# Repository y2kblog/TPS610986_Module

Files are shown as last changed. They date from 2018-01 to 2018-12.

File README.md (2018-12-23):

# TPS610986 超低消費電力 3.3V出力昇圧モジュール

<!--
<img src="/images/ProductImage_Front.jpg" width="200px">
-->
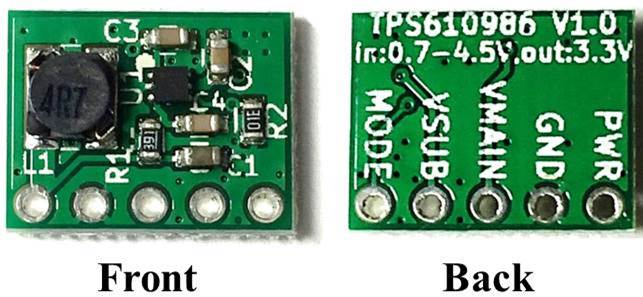
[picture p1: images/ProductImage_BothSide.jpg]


## 概要

超低消費電力の昇圧型DC-DCコンバータ TPS610986 (Texas Instruments Inc.製) を搭載したモジュールです。  
TPS610986の**静止電流は約1μA程度**（ローパワーモード時）と非常に低く、また**0.7Vから動作**するため、コイン電池1個、もしくはアルカリ／ニカド／ニッケル水素乾電池1～2本で駆動するアプリケーションに適しています。  
さらに、TPS610986は**ロードスイッチ機能付き**であり、MODEピンを利用することでVSUBピンのON/OFFの切り替えとローパワーモード（超低静止電流）／アクティブモード（高過渡応答）の選択が可能です。  
これにより、定期的にウェイクアップして動作し、それ以外の大半の時間はスリープするようなバッテリー駆動のアプリケーションにおいて、常時出力のVMAINピンをマイコン（MCU）に繋ぎ、VSUBピンをその他のサブシステム（センサ、GPS、無線モジュール、SDカード等）に接続すると、スリープ時はローパワーモードでマイコンのみに電力を供給することでバッテリー寿命を延ばし、動作時はアクティブモードでサブシステムにも高過渡応答の安定的な電力を供給する、といったことが可能です。  
<!--
TPS610986の静止電流は約1μA程度（ローパワーモード時）と非常に低いため、バッテリー駆動のアプリケーションに適しています。  
-->
<!--
スリープ時はローパワーモードでマイコンのみに電力を供給することでバッテリー寿命を延ばし、ウェイクアップ時はアクティブモードで良好な過渡応答を得ることができます。  
また、最大スイッチング電流は350mAであるため、SDカード等の比較的大電流を要するアプリケーションにも使用できます。
-->

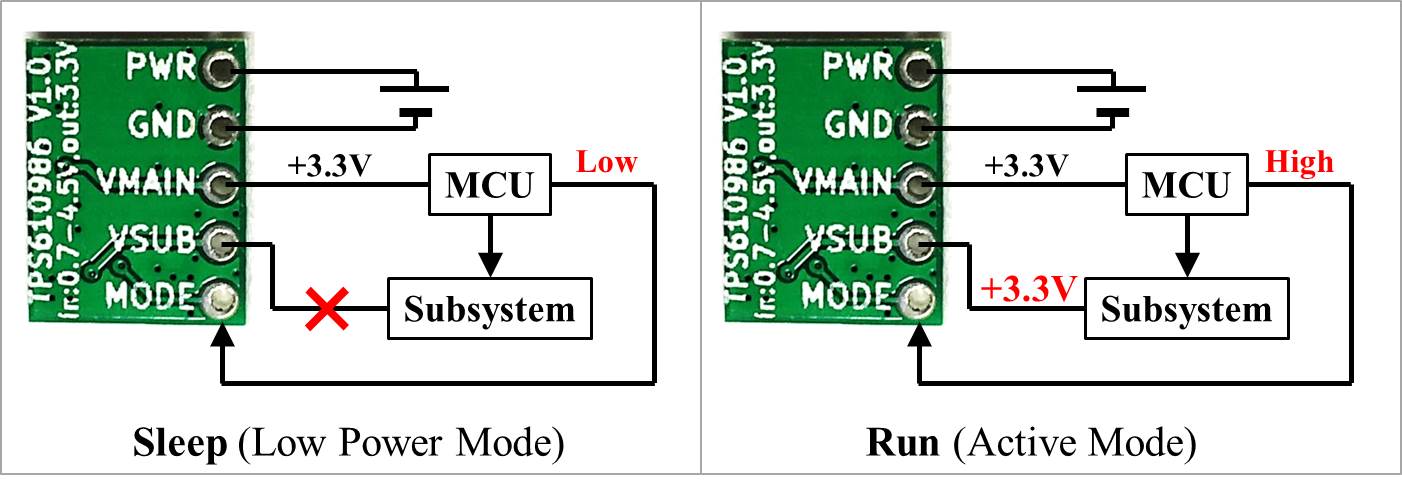
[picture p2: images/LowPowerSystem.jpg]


### 仕様
- 入力電圧：0.7V～4.5V (※3.3V以上入力した場合はパススルーとなります)
- 出力電圧：3.3V (低負荷のバーストモード時：3.4V)
- 最大スイッチング電流：350mA (※最大出力電流は入力電圧と効率に依存します)
- ロードスイッチ付
- 効率
  - 88% (入力電圧2V～3.3V、負荷10μA、ローパワーモード時)
  - 93% (入力電圧2V～3.3V、負荷5mA～100mA)
- 基板サイズ：横12.7mm×縦10.0ｍｍ

## 販売  
[スイッチサイエンス委託販売ページ](https://www.switch-science.com/catalog/3659/)  
※大量注文や在庫に関する問い合わせは[こちら](mailto:info.y2kb@gmail.com)までご連絡ください。  

### 回路図  
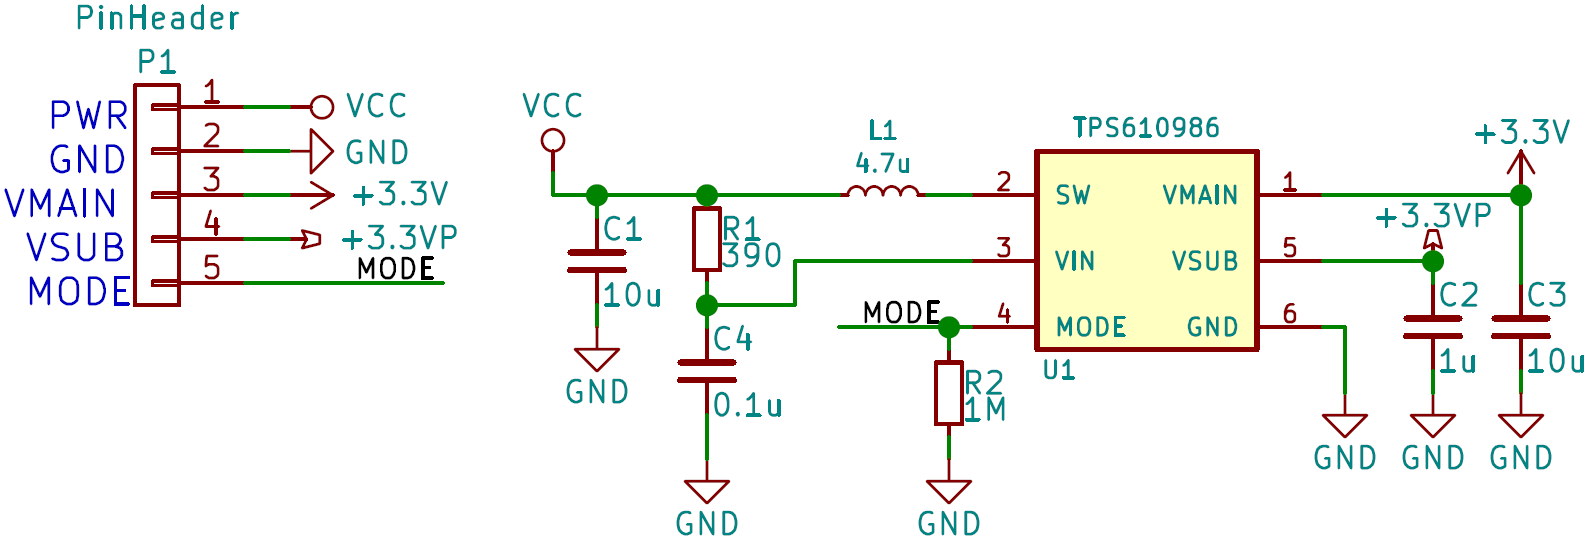
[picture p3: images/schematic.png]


### 寸法
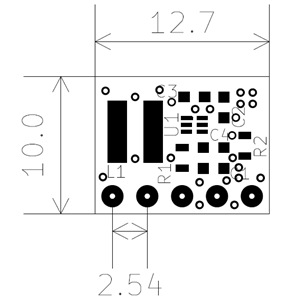
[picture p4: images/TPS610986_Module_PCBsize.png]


## 性能評価  

### 静止電流  
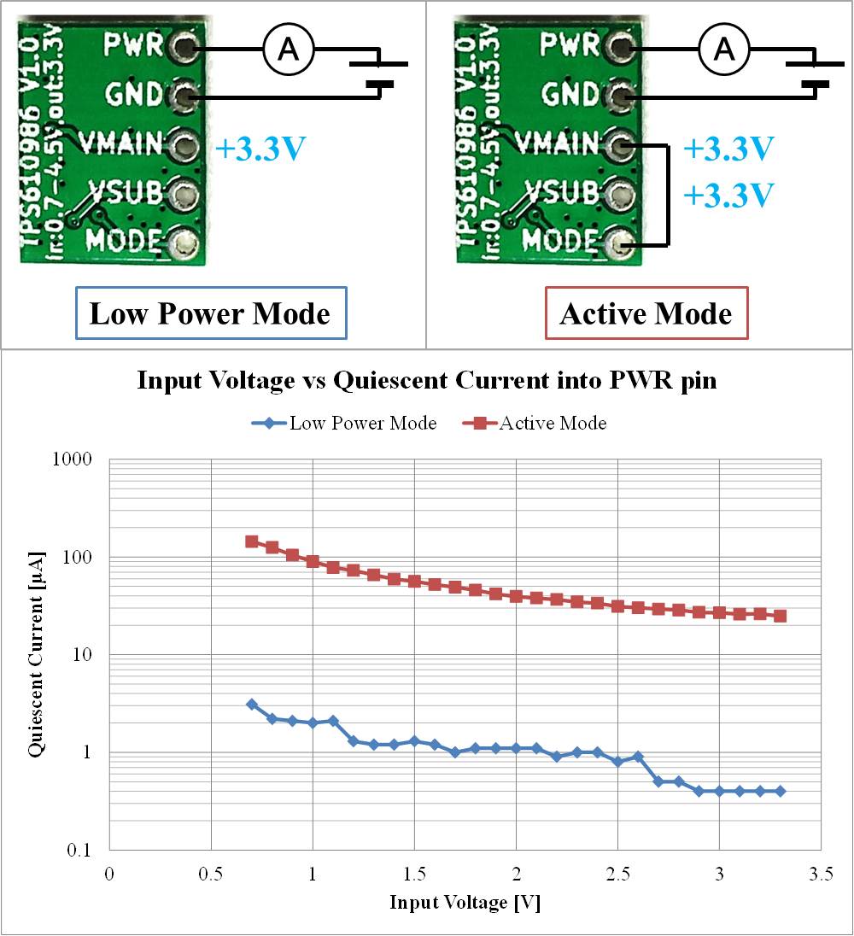
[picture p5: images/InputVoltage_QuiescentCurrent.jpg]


### 整定時間  

#### VSUBピンの整定時間（負荷：無し）：約800μs
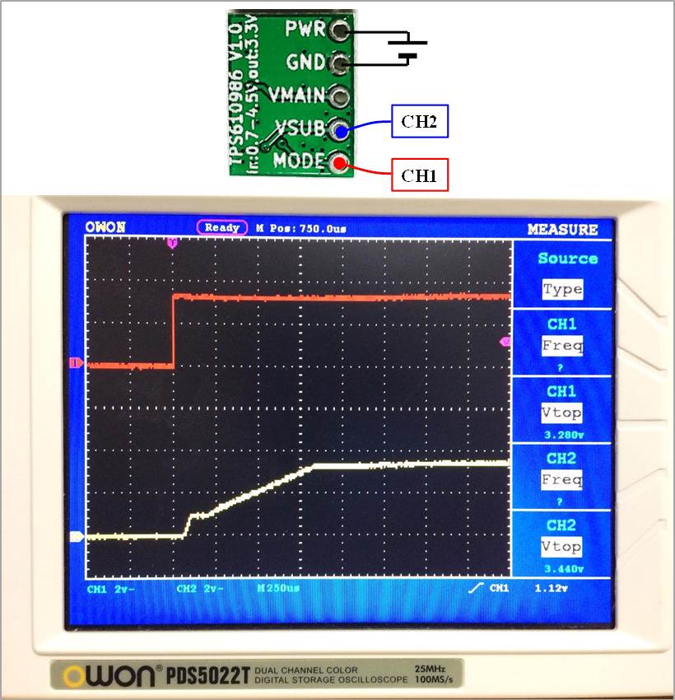
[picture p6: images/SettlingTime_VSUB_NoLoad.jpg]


#### VSUBピンの整定時間（負荷：210mA）：約760μs
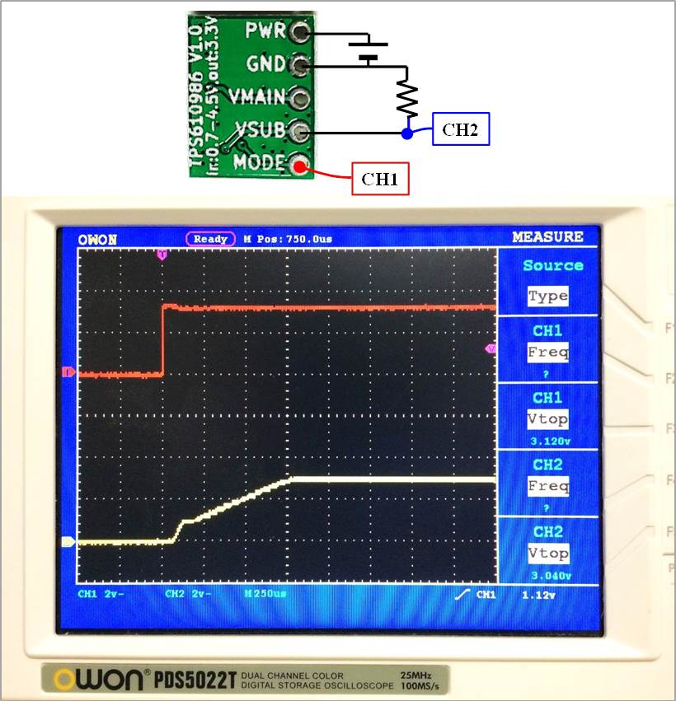
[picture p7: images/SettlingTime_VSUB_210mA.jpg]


#### VMAINピンの整定時間（負荷：無し）：約580μs
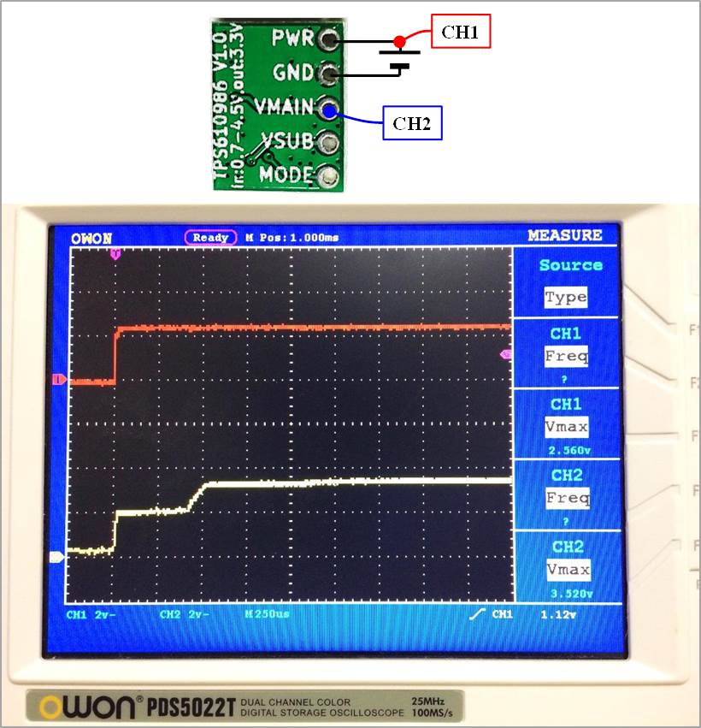
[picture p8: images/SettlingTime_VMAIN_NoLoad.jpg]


#### VMAINピンの整定時間（負荷：210mA）：約1500μs
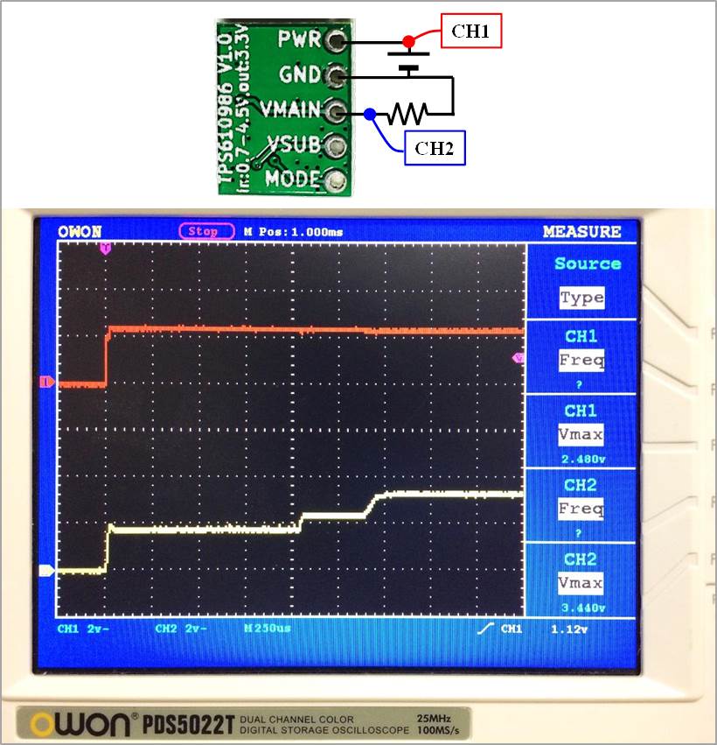
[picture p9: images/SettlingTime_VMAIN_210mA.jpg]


## データシート  
[TPS610986データシート(英語)](http://www.ti.com/lit/ds/symlink/tps610986.pdf)

## License
MIT License

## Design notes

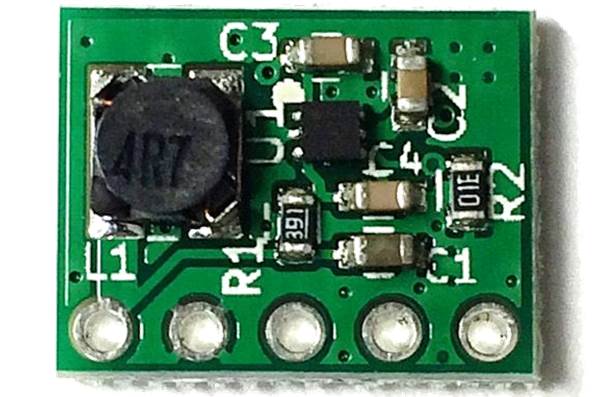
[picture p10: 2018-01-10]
images/ProductImage_Front.jpg

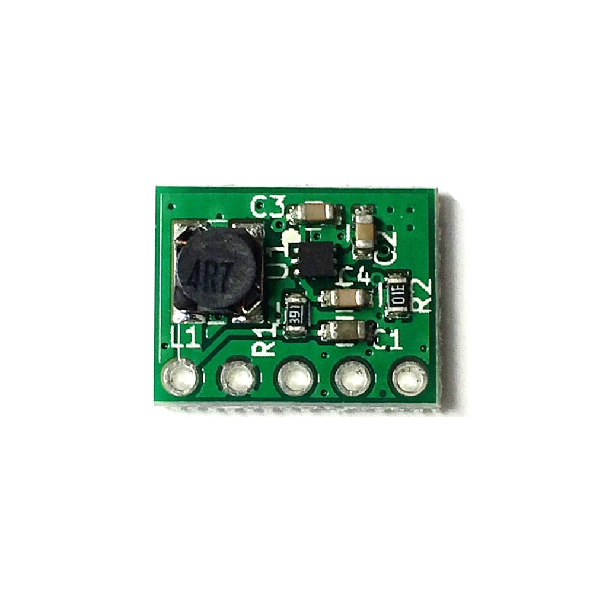
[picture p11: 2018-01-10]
images/ProductImage.jpg

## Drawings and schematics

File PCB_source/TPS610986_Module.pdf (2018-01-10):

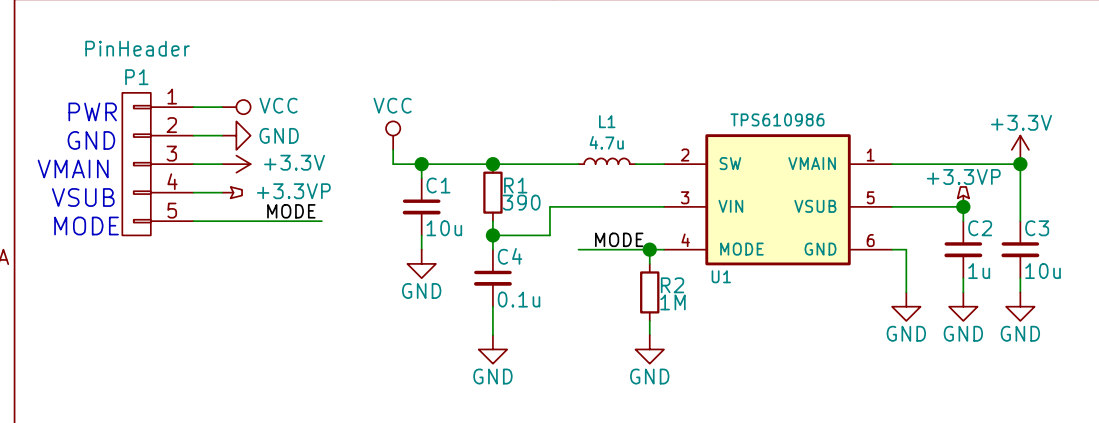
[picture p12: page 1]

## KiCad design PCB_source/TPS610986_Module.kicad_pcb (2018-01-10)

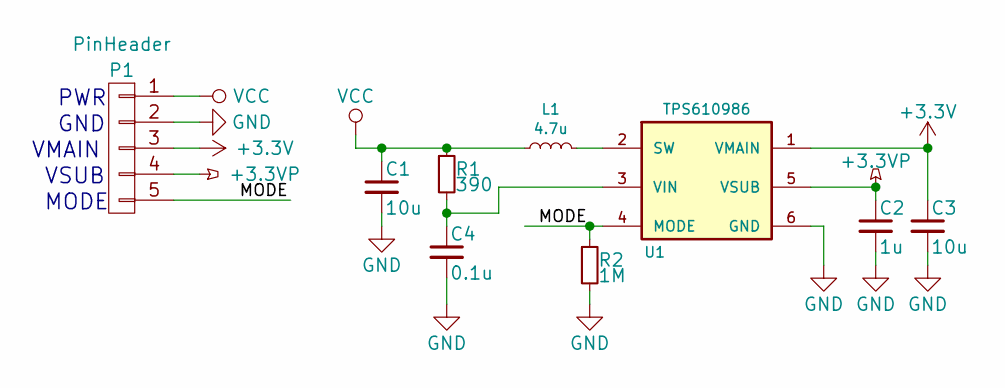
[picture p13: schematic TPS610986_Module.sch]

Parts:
C1, C3: 10u; C_0603
C2: 1u; C_0603
C4: 0.1u; C_0603
L1: 4.7u; USER_L_SPD3D16
P1: PinHeader; USER_SIL-5_NoSilk
R1: 390; R_0603
R2: 1M; R_0603
U1: TPS610986; USER_Boost_TPS61098x

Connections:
+3.3VP: C2.1, P1.4, U1.5 (VSUB)
+3V3: C3.1, P1.3, U1.1 (VMAIN)
/MODE: P1.5, R2.1, U1.4 (MODE)
GND: C1.2, C2.2, C3.2, C4.2, P1.2, R2.2, U1.6 (GND)
unnamed: C4.1, R1.2, U1.3 (VIN)
unnamed: L1.2, U1.2 (SW)
VCC: C1.1, L1.1, P1.1, R1.1

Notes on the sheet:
PWR
GND
VMAIN
VSUB
MODE

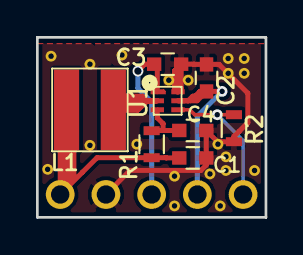
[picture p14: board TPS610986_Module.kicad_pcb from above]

Board: 2 copper layers, 12.7 x 10.0 mm, 29 parts (0 on the bottom side), 7 nets.

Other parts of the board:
11, 12, 13, 14, 15, 21, 22, 23, 24, 25, 31, 32, 33, 34, 34#2, 35, 44, 45, 54, 55: USER_GNDvia
